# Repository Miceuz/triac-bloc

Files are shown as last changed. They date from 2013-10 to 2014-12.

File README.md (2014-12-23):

triac-bloc
==========

A universal power block based on triac. In essence this is a high power solid state relay augmented with some bells and whistles. 

TRIAC BLOC

Bells and whistles:

 * Attiyny44 MCU on board
 * I2C interface
 * maximum power - 6kW
 * zero crossing detection
 * controllable via I2C protocol
 * phase shift dimmer mode
 * linear output power control
 * switch at zero-crossing mode
 * output filtering for dimmer mode
 * snubber network
 * “low level” zero-crossing signal output
 * “low level” triac trigger signal input
 * 4 spare MCU pins available for additional features
 * open source hardware and firmware

More info available at: http://wemakethings.net/2013/10/27/triac-bloc/

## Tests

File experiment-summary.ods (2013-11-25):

input R | pull up R | ZC pulse |  |  |  |  |  | Period length
 |  | mean | median | min | max | Max-min | diff abs median | mean | median | min | max | Max-min | diff abs median
32.8k | 47k | 0.359 | 0.358 | 0.335 | 0.371 | 0.036 | 0.001875 | 9.9778 | 9.9775 | 9.923 | 10.0415 | 0.1185 | 0.037
32.8k | 10k | 0.54 | 0.54 | 0.494 | 0.561 | 0.067 | 0.003975 | 9.9788 | 9.9620 | 9.939 | 10.0175 | 0.0785 | 0.059
16.4k | 10k | 0.302 | 0.302 | 0.280 | 0.312 | 0.032 | 0.001625 | 9.9781 | 9.9770 | 9.917 | 10.0750 | 0.1585 | 0.029
16.4k | 1k | 1.1598 | 1.164 | 1.102 | 1.205 | 0.103 | 0.001969

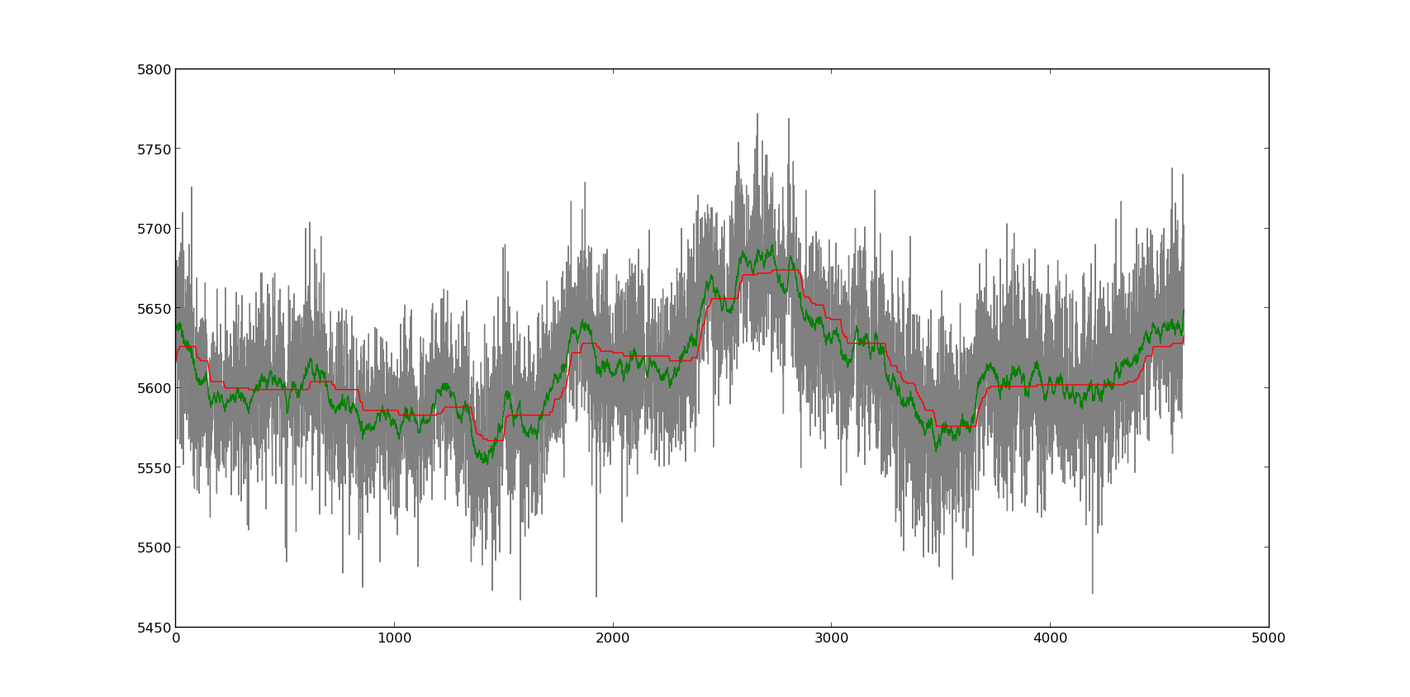
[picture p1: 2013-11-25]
experiment2/zc-pulse-length-noise3.png

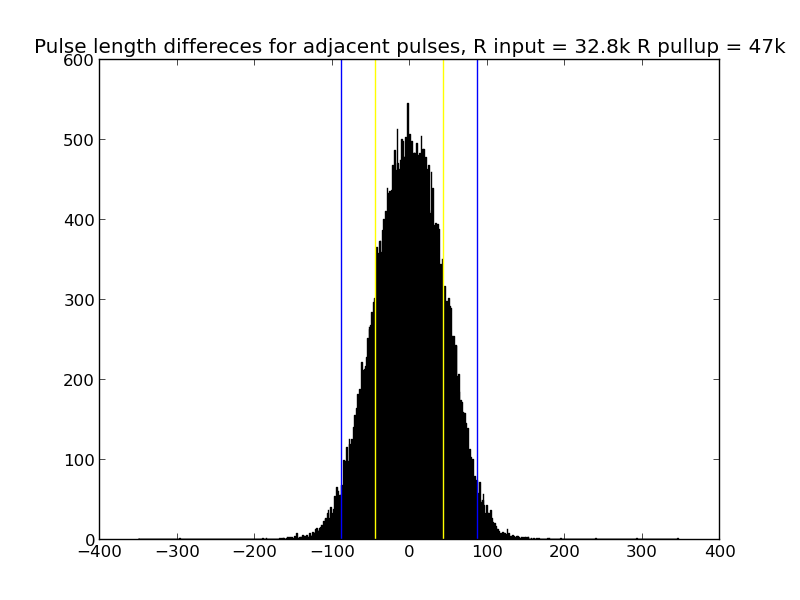
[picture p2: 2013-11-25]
experiment2/Pulse length differeces for adjacent pulses, R input = 32k8 R pullup = 47k.png

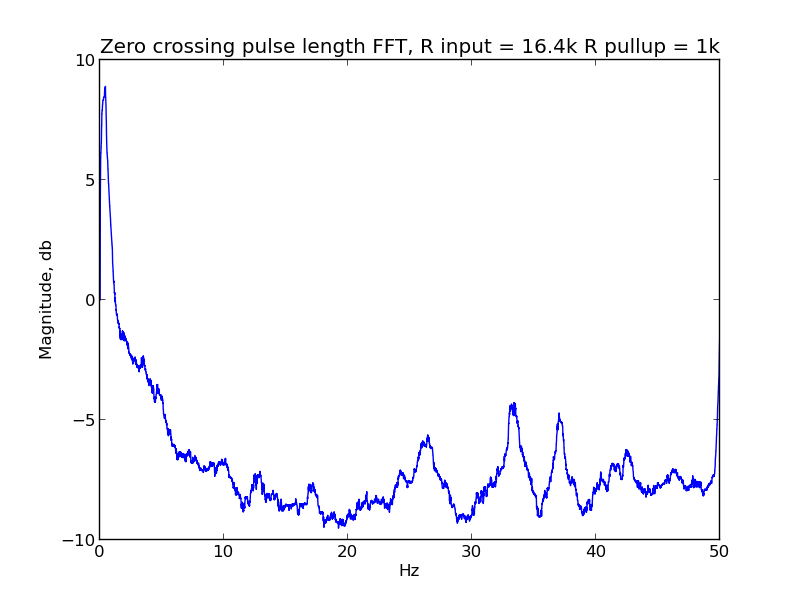
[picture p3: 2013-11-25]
experiment3/Zero crossing pulse length FFT, R input = 16k4 R pullup = 1k.png

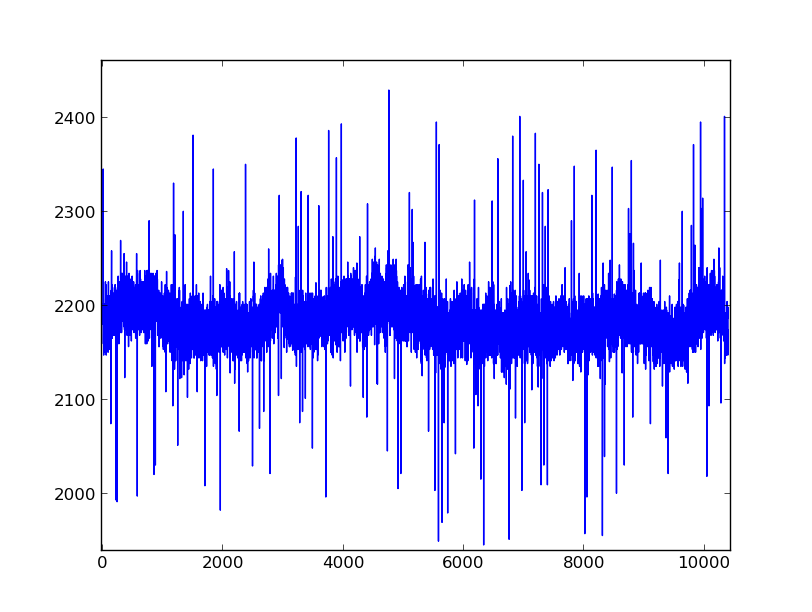
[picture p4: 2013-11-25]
experiment2/zc-pulse-length-noise.png

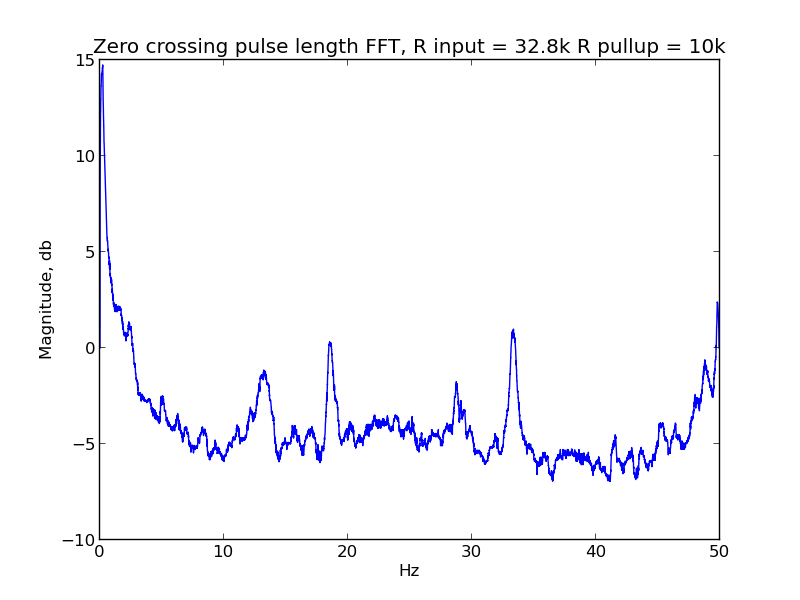
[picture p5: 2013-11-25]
experiment3/Zero crossing pulse length FFT, R input = 32k8 R pullup = 10k.png

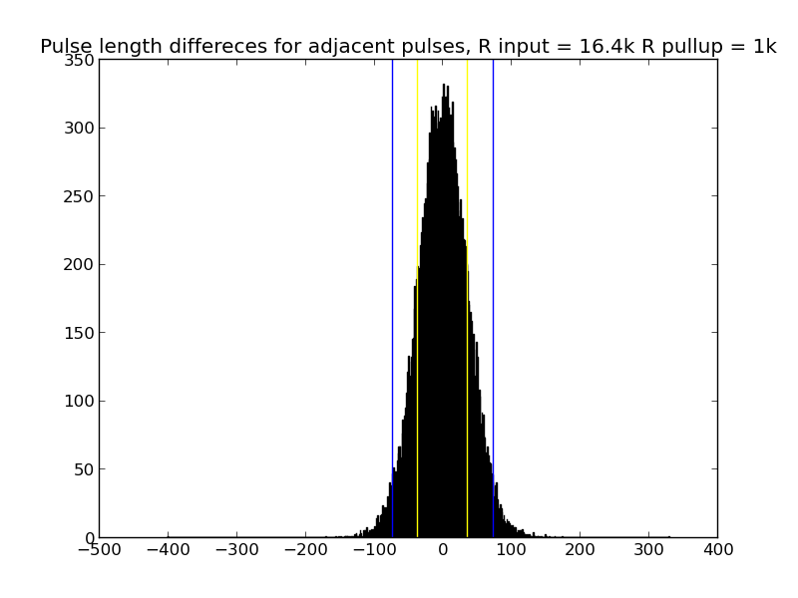
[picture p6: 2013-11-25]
experiment2/Pulse length differeces for adjacent pulses, R input = 16k4 R pullup = 1k.png

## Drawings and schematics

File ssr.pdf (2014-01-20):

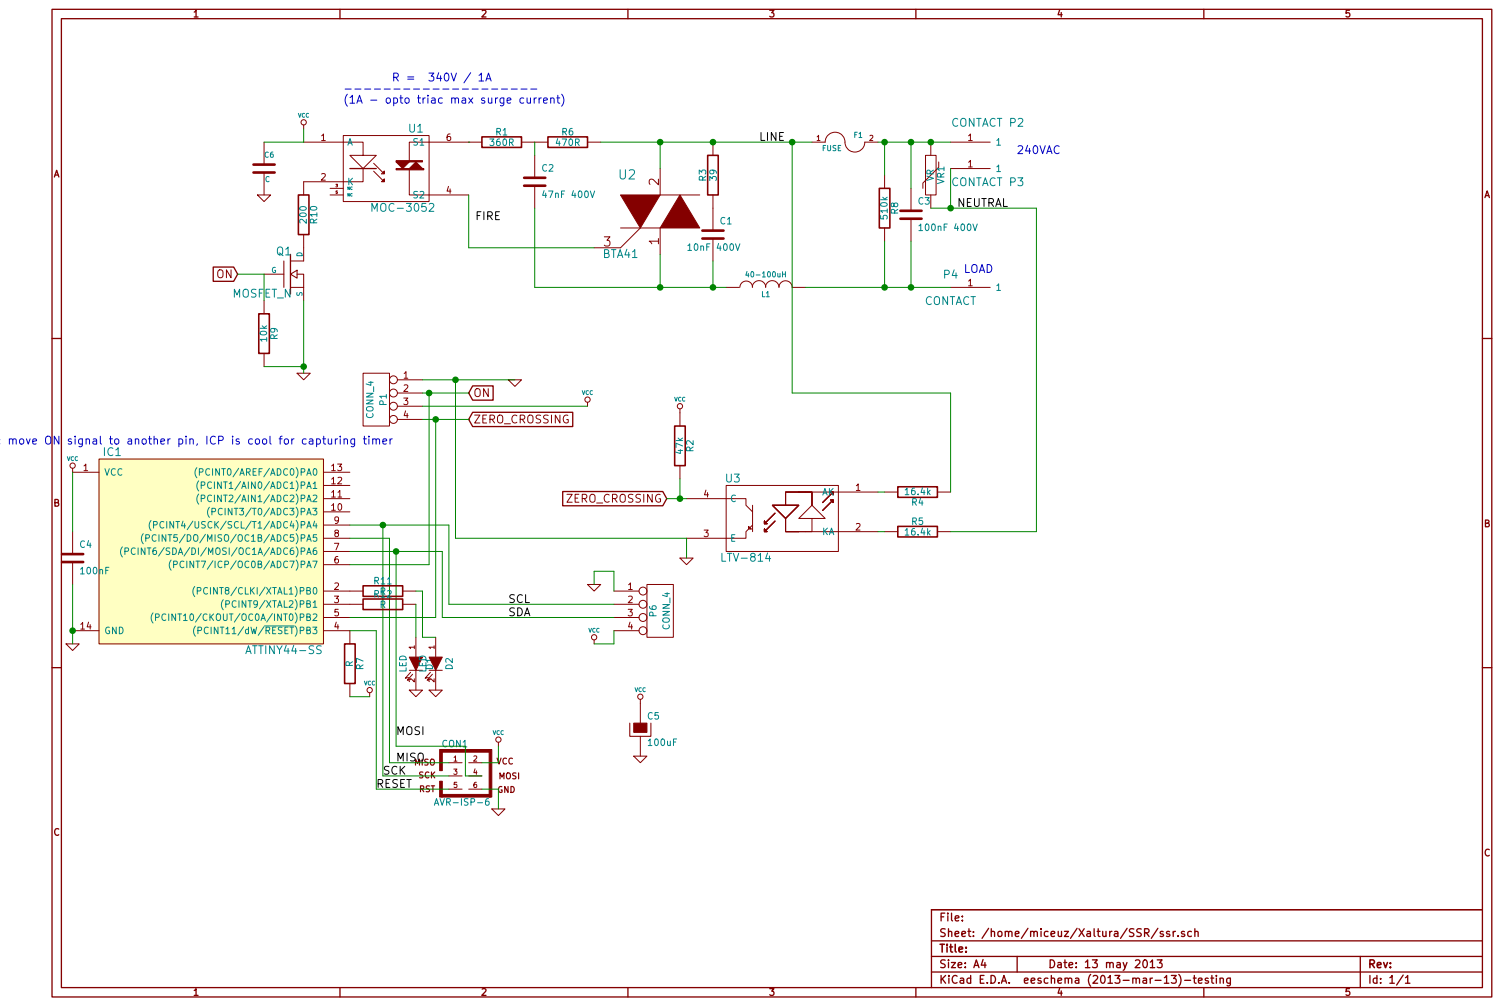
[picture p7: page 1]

TODO: move ON signal to another pin, ICP is cool for capturing timer

C Sheet: /home/miceuz/Xaltura/SSR/ssr.sch File: Title:

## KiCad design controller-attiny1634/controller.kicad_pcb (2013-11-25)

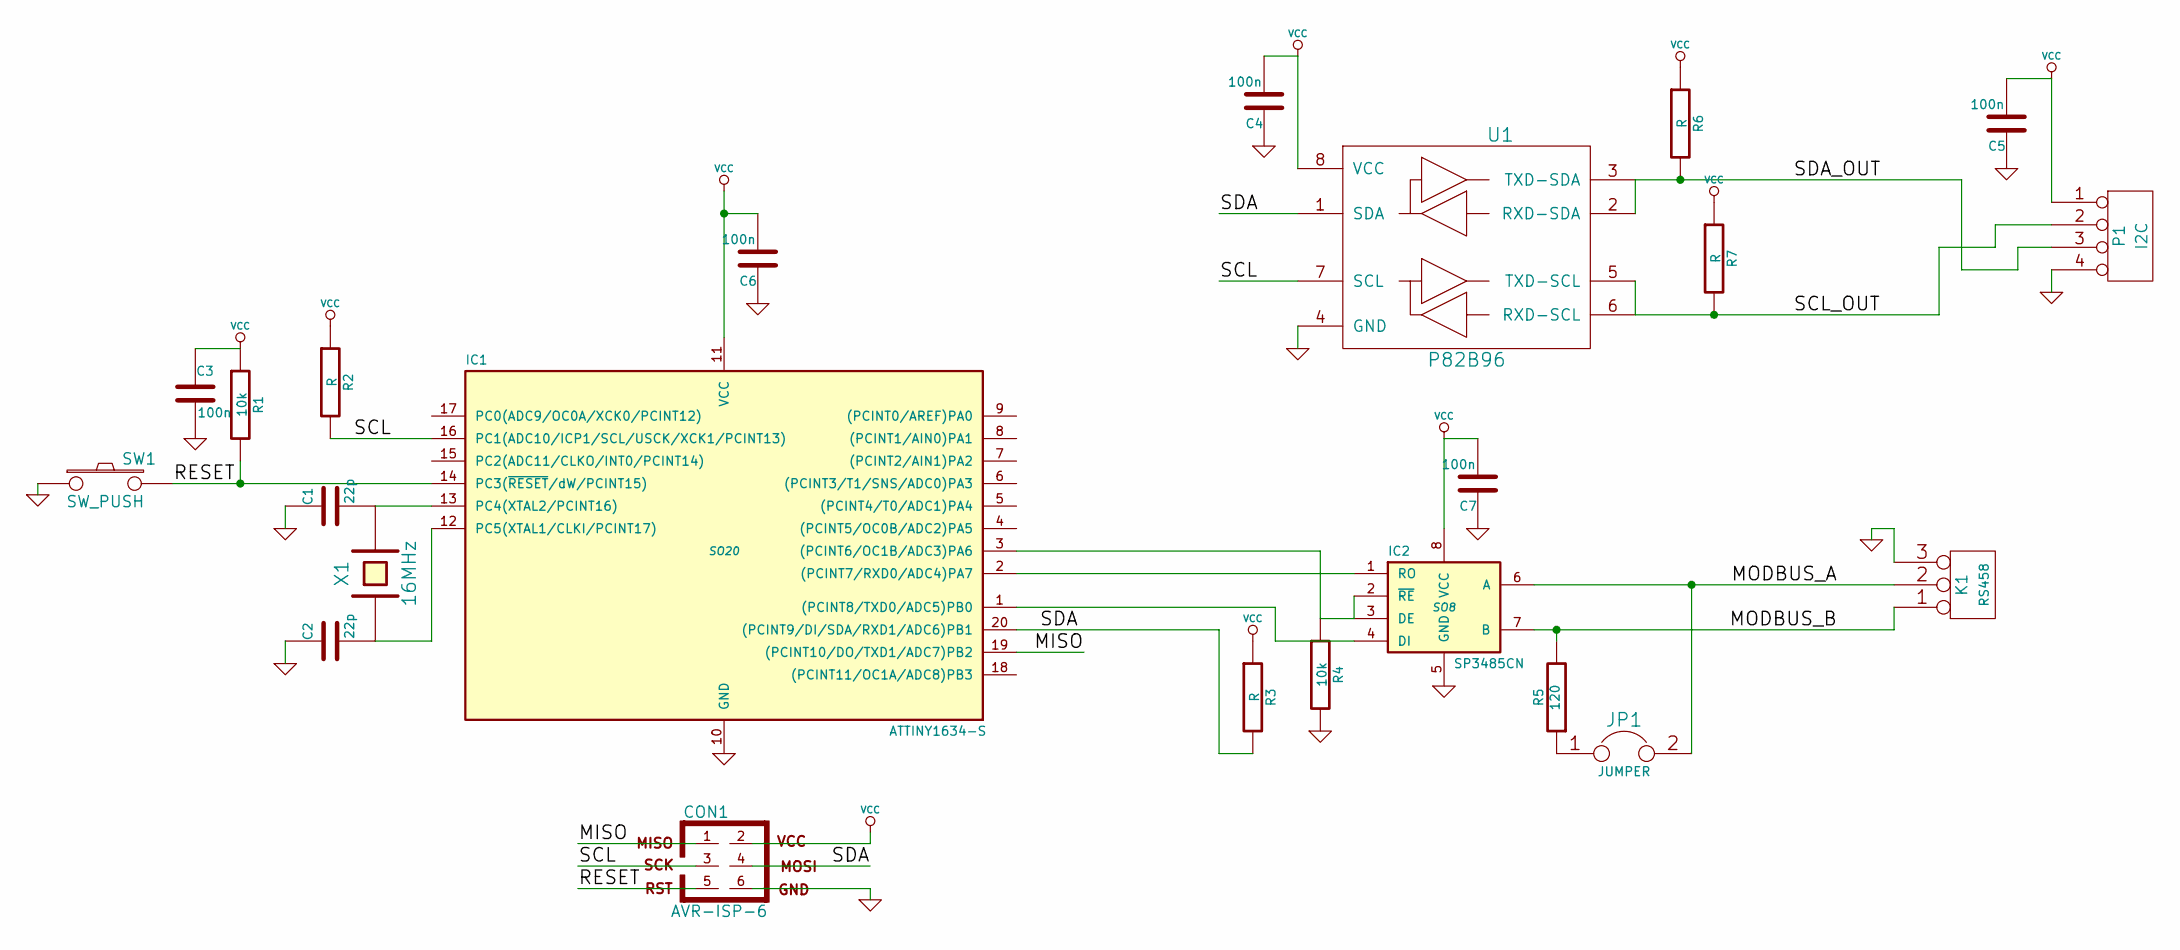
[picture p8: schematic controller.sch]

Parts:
C1, C2: 22p
C3, C4, C5, C6, C7: 100n
CON1: AVR-ISP-6
IC1: ATTINY1634-S; SO20
IC2: SP3485CN; SO8
JP1: JUMPER
K1: RS458
P1: I2C
R1, R4: 10k
R2, R3, R6, R7: R
R5: 120
SW1: SW_PUSH
U1: P82B96
X1: 16MHz

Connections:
/MISO: CON1.1, IC1.19 ((PCINT10/DO/TXD1/ADC7)PB2)
/MODBUS_A: IC2.6 (A), JP1.2, K1.2 (PM)
/MODBUS_B: IC2.7 (B), K1.1, R5.2
/RESET: CON1.5, IC1.14 (PC3(~RESET~/dW/PCINT15)), R1.2, SW1.2
/SCL: CON1.3, IC1.16 (PC1(ADC10/ICP1/SCL/USCK/XCK1/PCINT13)), R2.2, U1.7 (SCL)
/SCL_OUT: P1.2, R7.2, U1.5 (TXD-SCL), U1.6 (RXD-SCL)
/SDA: CON1.4, IC1.20 ((PCINT9/DI/SDA/RXD1/ADC6)PB1), R3.2, U1.1 (SDA)
/SDA_OUT: P1.3, R6.2, U1.2 (RXD-SDA), U1.3 (TXD-SDA)
GND: C1.1, C2.1, C3.2, C4.1, C5.1, C6.1, C7.1, CON1.6, IC1.10 (GND), IC2.5 (GND), K1.3, P1.4, R4.2, SW1.1, U1.4 (GND)
unnamed: C1.2, IC1.13 (PC4(XTAL2/PCINT16)), X1.2
unnamed: C2.2, IC1.12 (PC5(XTAL1/CLKI/PCINT17)), X1.1
unnamed: IC1.2 ((PCINT7/RXD0/ADC4)PA7), IC2.1 (RO)
unnamed: JP1.1, R5.1
unnamed: IC1.3 ((PCINT6/OC1B/ADC3)PA6), IC2.2 (~RE~), IC2.3 (DE), R4.1
unnamed: IC1.1 ((PCINT8/TXD0/ADC5)PB0), IC2.4 (DI)
VCC: C3.1, C4.2, C5.2, C6.2, C7.2, CON1.2, IC1.11 (VCC), IC2.8 (VCC), P1.1, R1.1, R2.1, R3.1, R6.1, R7.1, U1.8 (VCC)

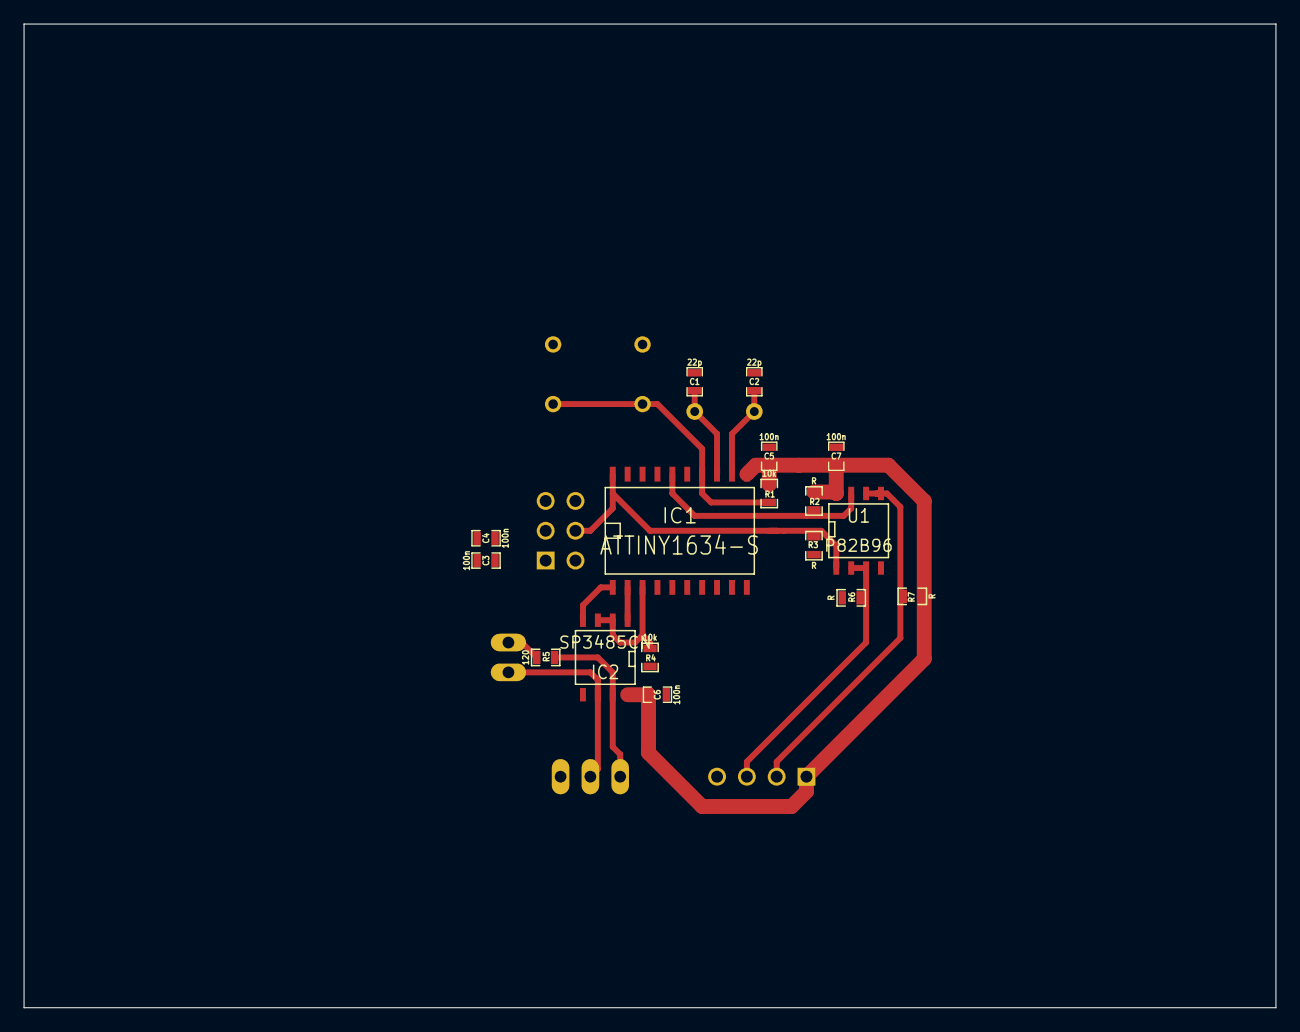
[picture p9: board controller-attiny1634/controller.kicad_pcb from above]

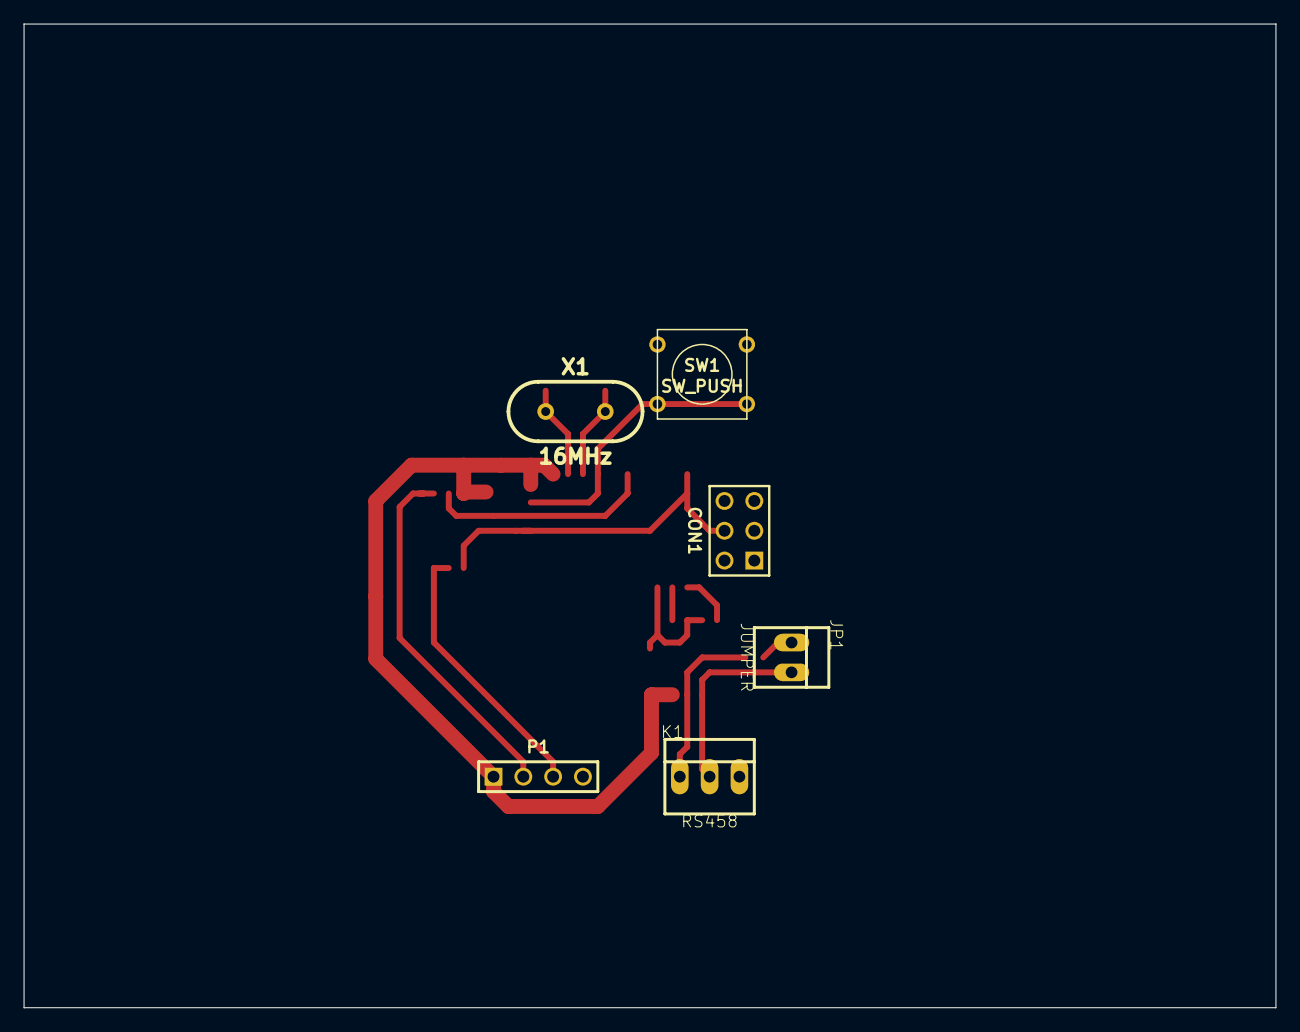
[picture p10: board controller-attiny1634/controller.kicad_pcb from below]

Board: 2 copper layers, 106.7 x 83.8 mm, 23 parts (6 on the bottom side), 16 nets.

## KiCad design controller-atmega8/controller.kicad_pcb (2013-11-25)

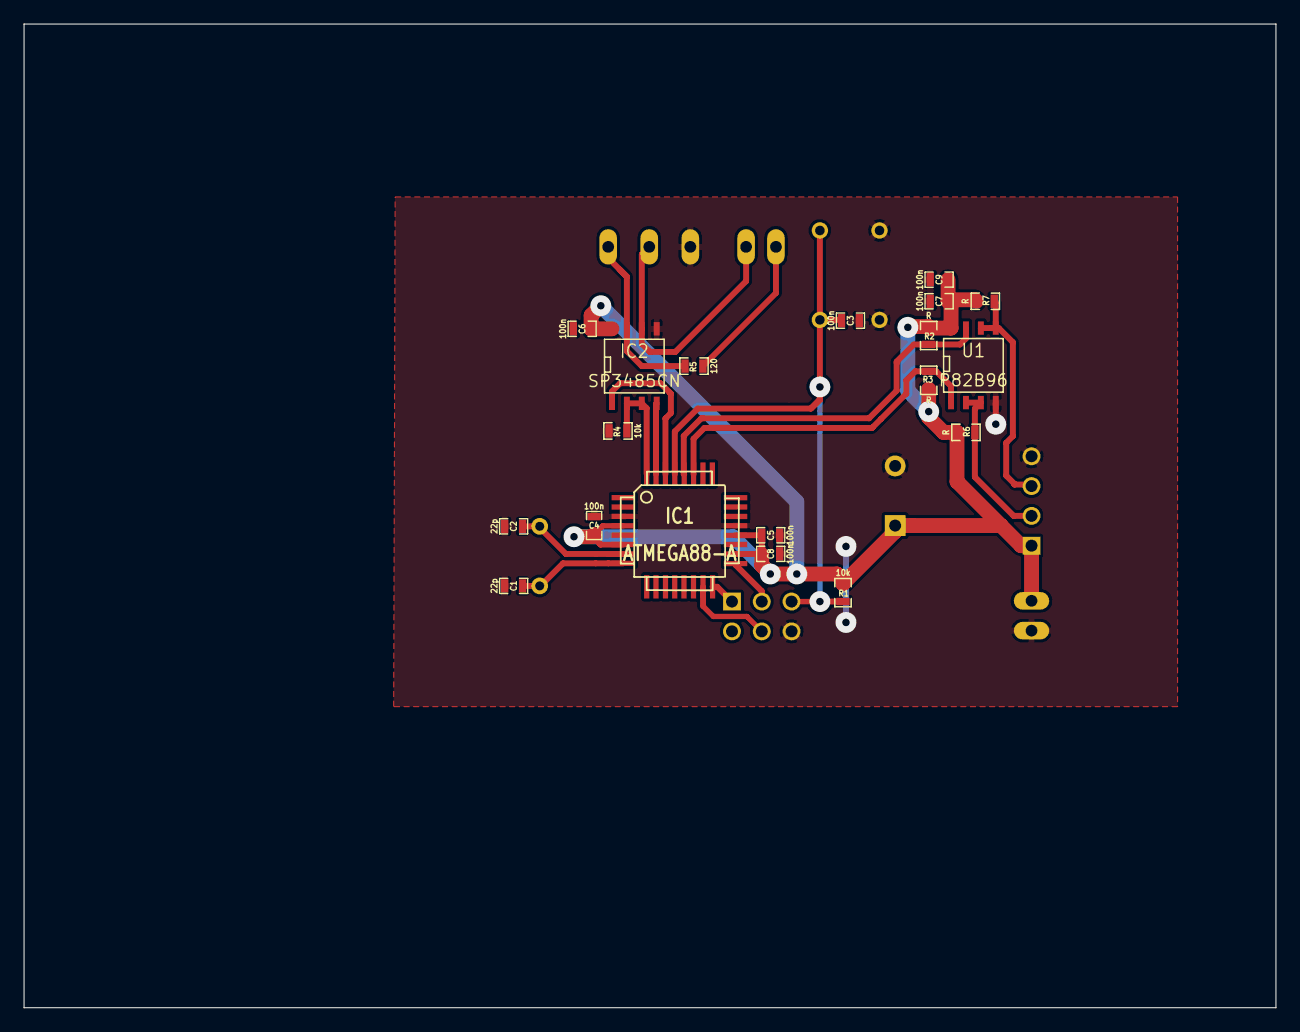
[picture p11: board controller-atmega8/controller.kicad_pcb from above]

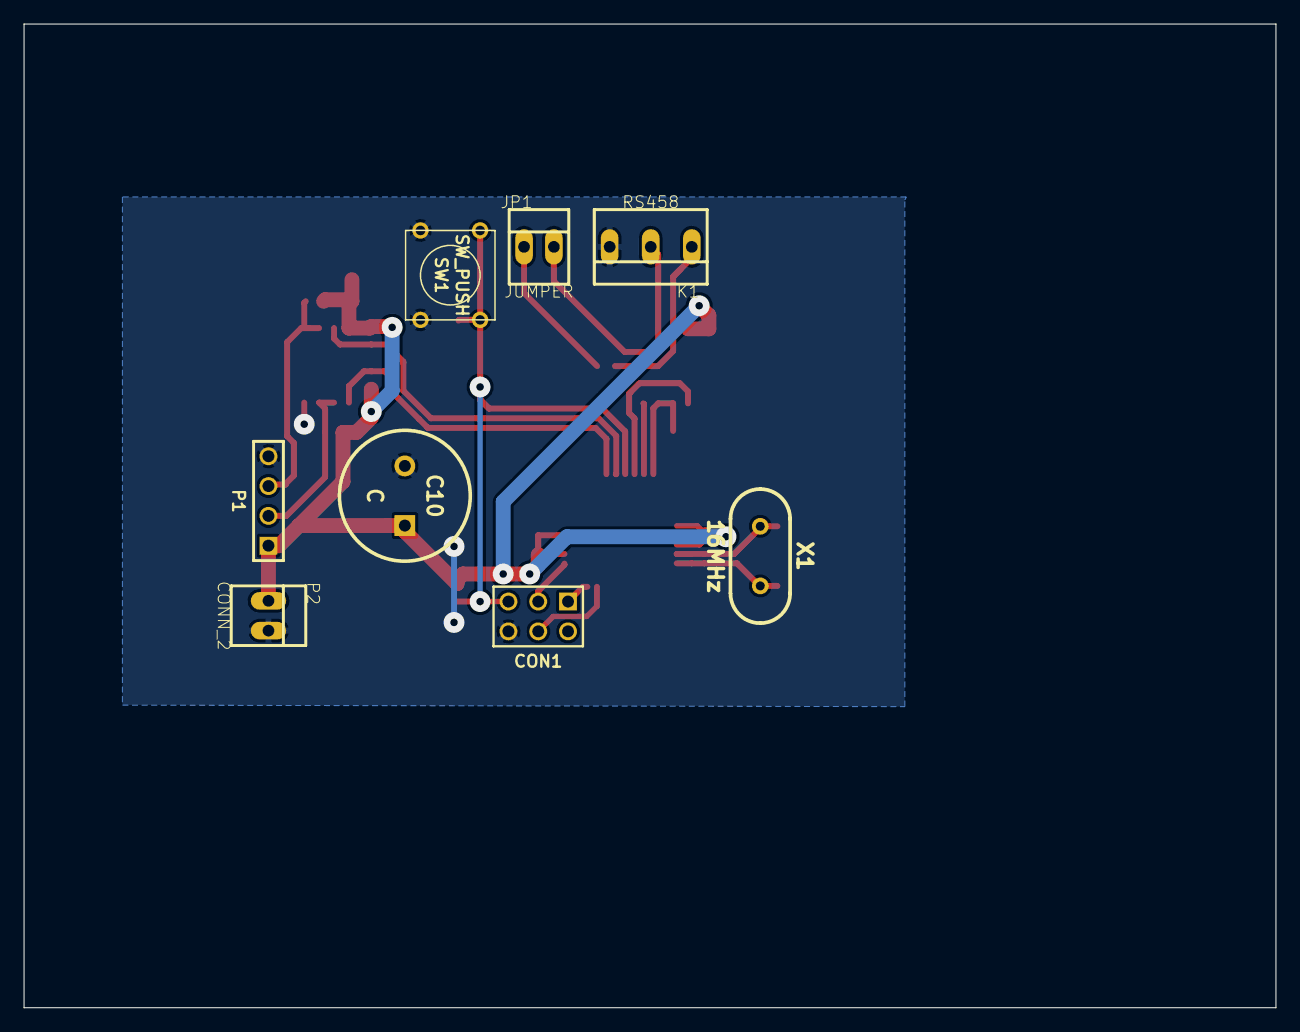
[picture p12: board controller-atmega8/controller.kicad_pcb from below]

Board: 2 copper layers, 106.7 x 83.8 mm, 27 parts (8 on the bottom side), 18 nets.

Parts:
C1, C2: 22p; SM0603_Capa
C3, C4, C5, C6, C7, C8, C9: 100n; SM0603_Capa
C10: C; C2V10
CON1: AVR-ISP-6; pin_array_3x2
IC1: ATMEGA88-A; TQFP32
IC2: SP3485CN; SO8N
JP1: JUMPER; PINHEAD1-2
K1: RS458; PINHEAD1-3
P1: I2C; PIN_ARRAY_4x1
P2: CONN_2; PINHEAD1-2
R1, R4: 10k; SM0603_Resistor
R2, R3, R6, R7: R; SM0603_Resistor
R5: 120; SM0603_Resistor
SW1: SW_PUSH; SW_PUSH_SMALL
U1: P82B96; SO8N
X1: 16MHz; HC-49V

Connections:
/DRIVER_ENABLE: IC1.32, IC2.2, IC2.3, R4.1
/MISO: CON1.1, IC1.16
/MODBUS_A: IC2.6, JP1.2, K1.2
/MODBUS_B: IC2.7, K1.1, R5.2
/MOSI: CON1.4, IC1.15
/RESET: C3.1, CON1.5, IC1.29, R1.2, SW1.2
/SCK: CON1.3, IC1.17
/SCL: IC1.28, R2.2, U1.7
/SCL_OUT: P1.3, R7.2, U1.5, U1.6
/SDA: IC1.27, R3.2, U1.1
/SDA_OUT: P1.2, R6.2, U1.2, U1.3
GND: C1.1, C2.1, C3.2, C4.1, C5.1, C6.1, C7.1, C8.1, C9.1, C10.2, CON1.6, IC1.3, IC1.5, IC1.21, IC2.5, K1.3, P1.4, P2.2, R4.2, SW1.1, U1.4
unnamed: IC1.30, IC2.1
unnamed: IC1.31, IC2.4
unnamed: C2.2, IC1.7, X1.1
unnamed: C1.2, IC1.8, X1.2
unnamed: JP1.1, R5.1
VCC: C4.2, C5.2, C6.2, C7.2, C8.2, C9.2, C10.1, CON1.2, IC1.4, IC1.6, IC1.18, IC1.20, P1.1, P2.1, R1.1, R2.1, R3.1, R6.1, R7.1, U1.8

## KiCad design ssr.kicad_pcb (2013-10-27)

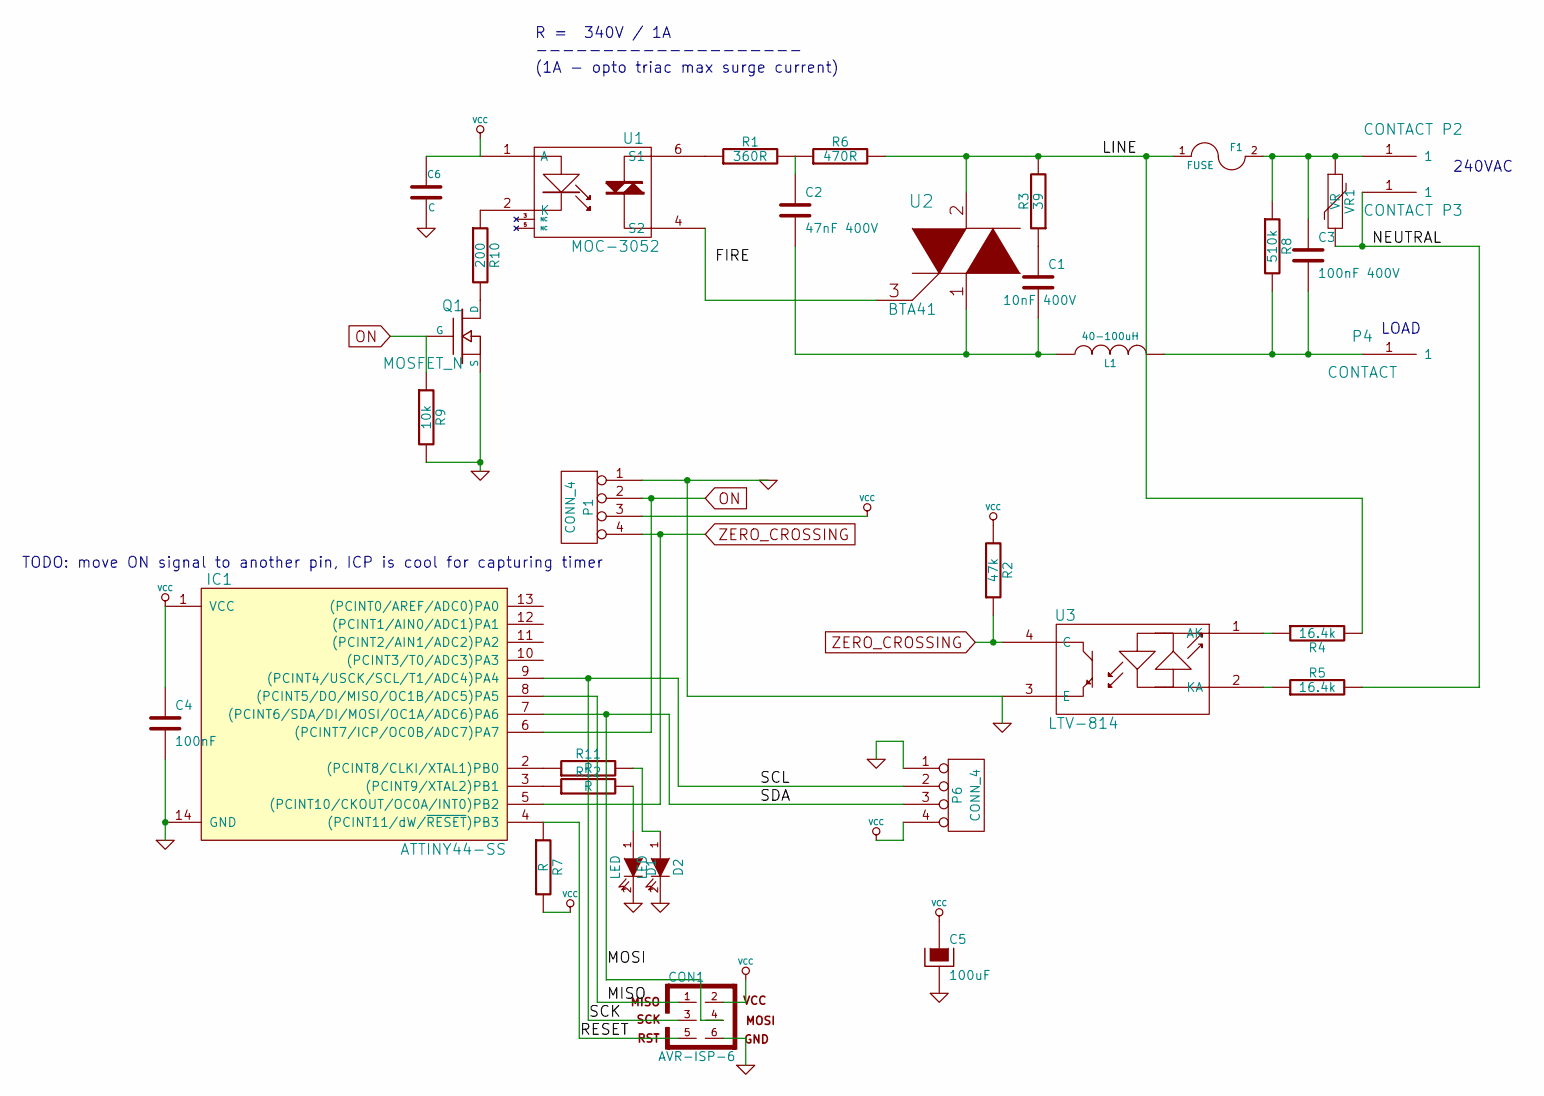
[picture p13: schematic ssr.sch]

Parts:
C1: 10nF 400V
C2: 47nF 400V
C3: 100nF 400V
C4: 100nF
C5: 100uF
C6: C
CON1: AVR-ISP-6
D1, D2: LED
F1: FUSE
IC1: ATTINY44-SS; SO14
L1: 40-100uH
P1, P6: CONN_4
P2, P3, P4: CONTACT
Q1: MOSFET_N
R1: 360R
R2: 47k
R3: 39
R4, R5: 16.4k
R6: 470R
R7, R11, R12: R
R8: 510k
R9: 10k
R10: 200
U1: MOC-3052
U2: BTA41
U3: LTV-814
VR1: VR

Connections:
/LINE: F1.1, F1.3, R3.2, R4.2, R6.2, U2.2
/MISO: CON1.1, IC1.8 ((PCINT5/DO/MISO/OC1B/ADC5)PA5)
/MOSI: CON1.4, IC1.7 ((PCINT6/SDA/DI/MOSI/OC1A/ADC6)PA6), P6.3
/NEUTRAL: P3.1, R5.2, VR1.2; also elsewhere on the board
/RESET: CON1.5, IC1.4 ((PCINT11/dW/~RESET~)PB3), R7.1
/SCK: CON1.3, IC1.9 ((PCINT4/USCK/SCL/T1/ADC4)PA4), P6.2
GND: C4.2, C5.2, C6.2, CON1.6, D1.2 (K), D2.2 (K), IC1.14 (GND), P1.1, P6.1, Q1.S, R9.2, U3.3 (E)
unnamed: U1.4 (S2), U2.3
unnamed: R5.1, U3.2 (KA)
unnamed: R4.1, U3.1 (AK)
unnamed: C2.1, R1.2, R6.1
unnamed: R1.1, U1.6 (S1)
unnamed: C1.2, C2.2, L1.1, U2.1
unnamed: IC1.2 ((PCINT8/CLKI/XTAL1)PB0), R11.1
unnamed: D2.1 (A), R11.2
unnamed: IC1.3 ((PCINT9/XTAL2)PB1), R12.1
unnamed: D1.1 (A), R12.2
unnamed: C3.2, L1.2, P4.1, R8.2
unnamed: R10.1, U1.2 (K)
unnamed: Q1.D, R10.2
unnamed: C3.1, F1.2, F1.4, F1.5, P2.1, R8.1, VR1.1
unnamed: C1.1, R3.1
ON: IC1.6 ((PCINT7/ICP/OC0B/ADC7)PA7), P1.2, Q1.G, R9.1
VCC: C4.1, C5.1, C6.1, CON1.2, IC1.1 (VCC), P1.3, P6.4, R2.2, R7.2, U1.1 (A)
ZERO_CROSSING: IC1.5 ((PCINT10/CKOUT/OC0A/INT0)PB2), P1.4, R2.1, U3.4 (C)

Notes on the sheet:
240VAC
LOAD
R = 340V / 1A -------------------- (1A - opto triac max surge current)
TODO: move ON signal to another pin, ICP is cool for capturing timer

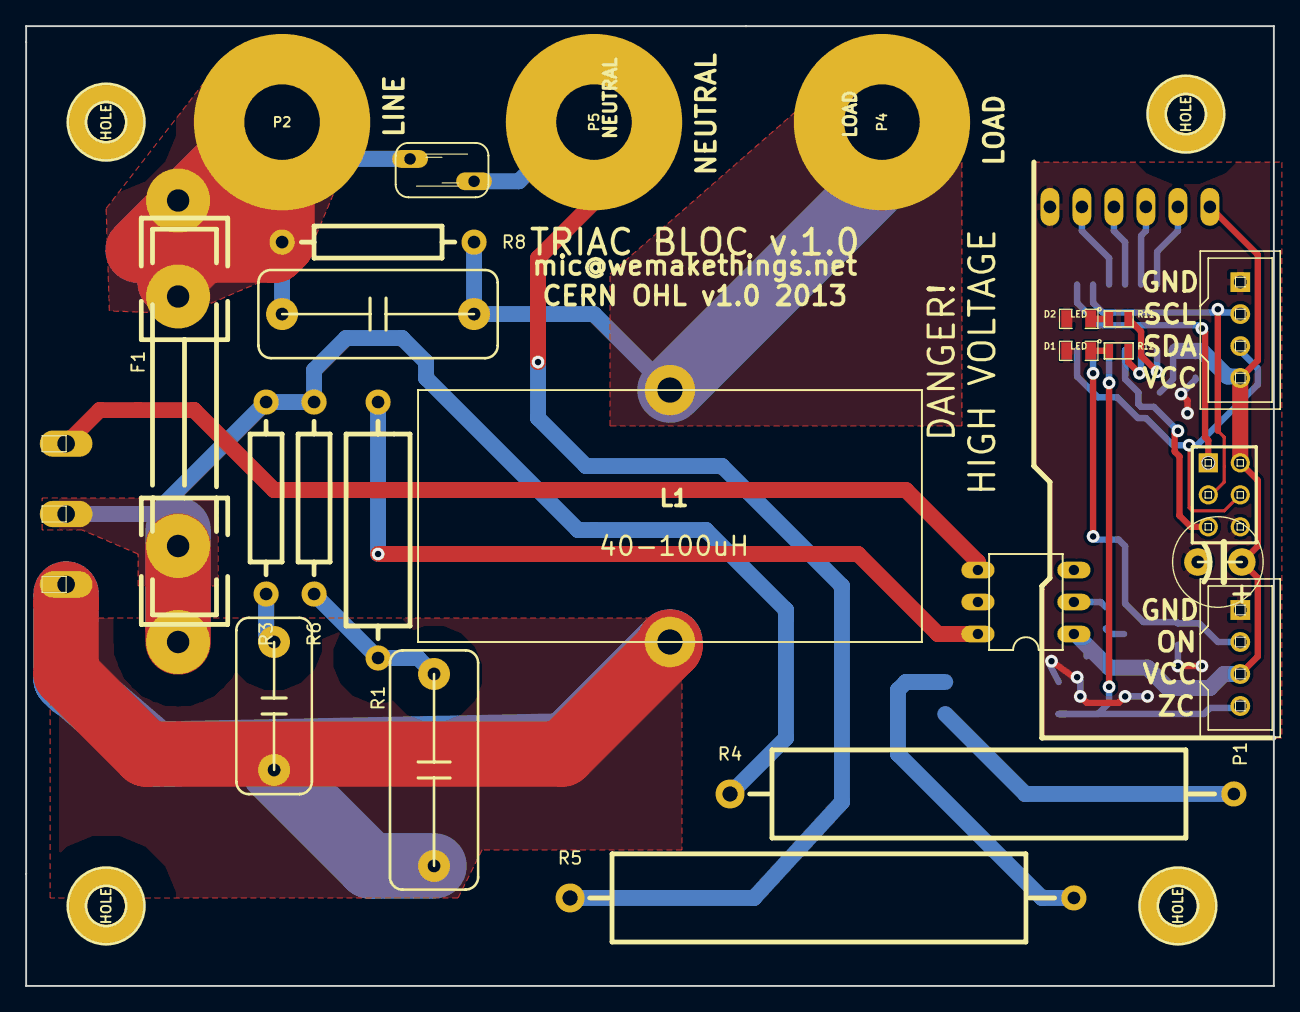
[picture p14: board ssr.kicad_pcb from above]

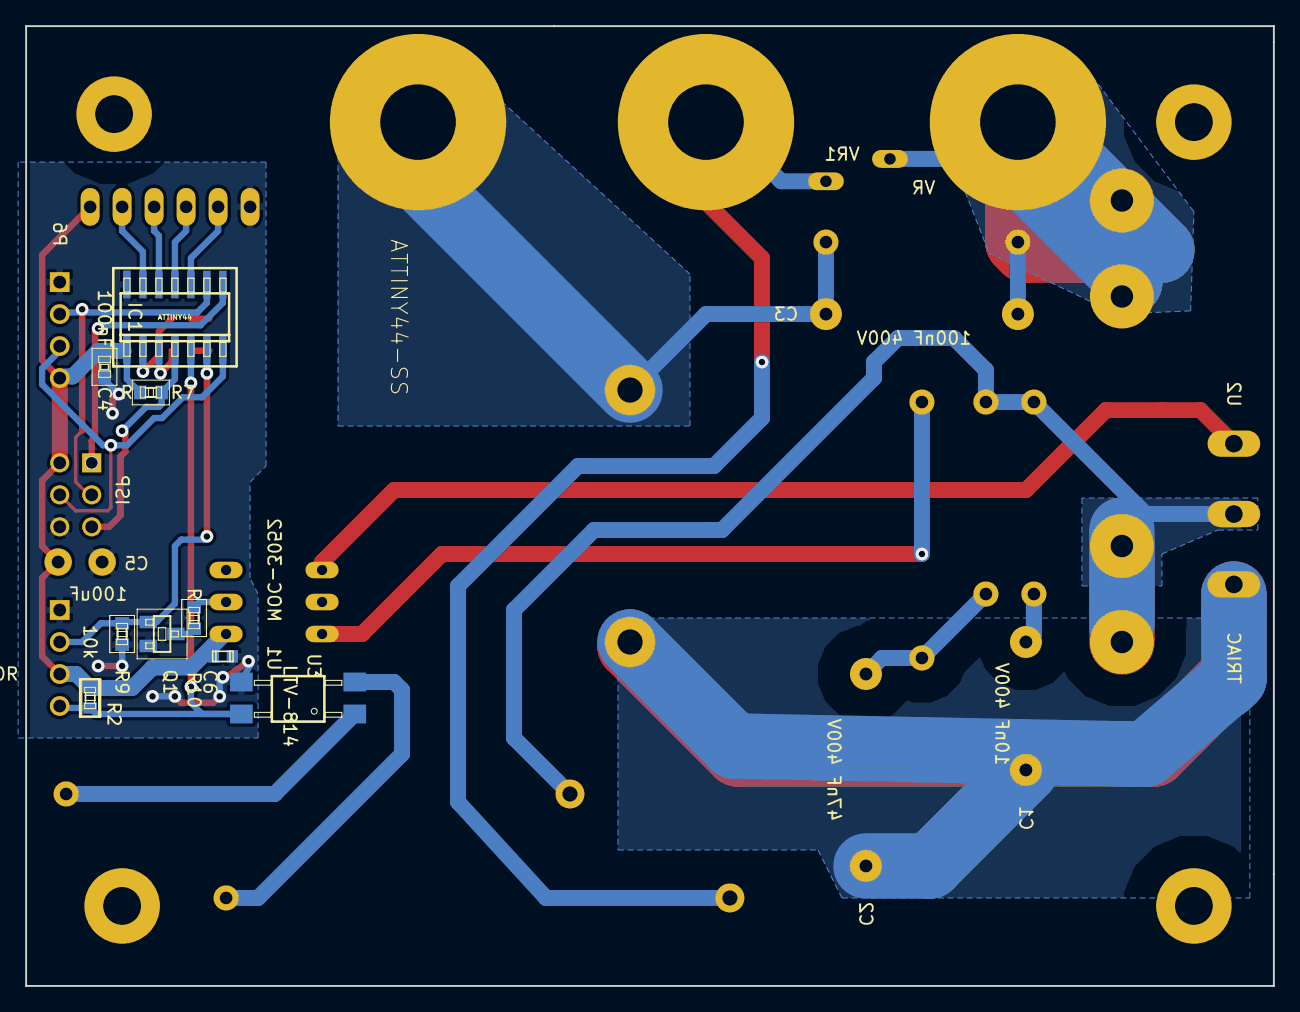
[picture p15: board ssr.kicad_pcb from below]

Board: 2 copper layers, 99.1 x 76.2 mm, 37 parts (9 on the bottom side), 24 nets.

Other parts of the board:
HOLE: Val**; HOLE_30
HOLE#2, HOLE#3, HOLE#4: Val**; HOLE_30
P5: CONTACT; HOLE_60

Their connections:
/NEUTRAL: P5.1; also elsewhere on the board

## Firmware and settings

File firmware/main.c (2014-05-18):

#include <inttypes.h>
#include <avr/io.h>
#include <stdlib.h>
#include <util/delay.h>
#include <avr/interrupt.h>
#include <avr/wdt.h>
#include <avr/sleep.h>
#include <avr/pgmspace.h>
#include <avr/wdt.h>
#include <avr/eeprom.h>
#include "usiTwiSlave.h"

#define GREEN PB0
#define RED PB1

/*
 * Sets the linear output power in dimmer mode. 1 byte argument: [0 - 255]
 */
#define I2C_SET_DIMMER_POWER 1
/*
 * Sets the linear output power in relay mode. 1 byte argument: [0 - 255]
 * In relay mode conduction is switched on after each ZC for the whole period {relayOutputPower} times in a row out of RELAY_MAX_POWER
 * thus, imitating a dimmer without causing electrical noise.
 */
#define I2C_SET_RELAY_POWER 2
/*
 * Directly sets the conduction angle. 2 bytes argument: [0 - 1000]
 */
#define I2C_SET_CONDUCTION_ANGLE 3
/*
 * Returns 2 bytes of filtered period length, represents the number of
 * internal timer ticks between two zero crossings.
 * Should be around 10000.
 * */
#define I2C_READ_PERIOD_LENGTH 4
/**
 * Returns 2 bytes of zero crossing pulse length.
 */
#define I2C_READ_ZC_PULSE_LENGHT 5
/**
 * Returns the 1 byte value of processor speed calibration register.
 */
#define I2C_READ_OSCCAL 6
/**
 * Returns 2 bytes of currently set conduction angle [0 - 10000]
 */
#define I2C_READ_CONDUCTION_ANGLE 7
/*
 * Returns 2 bytes of last period length, represents the number of
 * internal timer ticks between two zero crossings.
 * Should be around 10000.
 * */
#define I2C_READ_LAST_PERIOD_LENGTH 8
/**
 * Resets the Triac Bloc
 */
#define I2C_RESET 9
/**
 * Starts the calibration routine.
 * Red and green leds blink alternatingly while calibration is in progress.
 * Might take a while.
 */
#define I2C_CALIBRATE 10
#define I2C_ADC 11
/**
 * A routine for testing I2C connection. Both red and green leds will light up for a second.
 */
#define I2C_TEST 12

#define reset() wdt_enable(WDTO_15MS); while(1) {}

inline void conductionOn();
inline void conductionOff();
inline void setupZCInterrupt();
inline void setTimerInterruptAt(const uint16_t countTo, const uint8_t nextEvent);
inline void stopTimer();

#define NEVER 0
#define EVENT_TRUE_ZC 1
#define EVENT_CONDUCT 2

volatile uint8_t interruptAt = NEVER;
volatile uint16_t conductionAngle = 9000;
volatile uint16_t newConductionAngle = 9000;
volatile uint16_t zcPulseLength = 0;
volatile uint16_t periodLength = 0;
volatile uint8_t oscAjdustDelayCounter = 0;
volatile uint16_t zcInterruptTimestamp = 0;
extern const uint16_t conductionAngles[256];

#define EDGE_LEADING 0
#define EDGE_FALLING 1
#define MAX_SANE_ZC_LENGTH_DIFF 5
#define true 1
#define false 0

uint8_t zcInterruptEdge = EDGE_LEADING;
uint8_t powerGood = false;
uint8_t calibrationGood = false;

volatile uint8_t fadeIn = 1;
volatile uint8_t j = 255;
void fadeInOut() {
	if(fadeIn) {
		j --;
		if(j < 1) {
			fadeIn = !fadeIn;
		}
	} else {
		j ++;
		if(j > 254) {
			fadeIn = !fadeIn;
		}
	}
	newConductionAngle = pgm_read_word(&conductionAngles[j]);
}

inline void conductionOn() {
	PORTA |= _BV(PA7);
}

inline void conductionOff() {
	PORTA &= ~_BV(PA7);
}

inline void resetTimer() {
	TCNT1 = 0;
}

inline void setTimerInterruptAt(const uint16_t countTo, const uint8_t nextEvent) {
	TIMSK1 |= _BV(OCIE1A) | _BV(TOIE1);
	OCR1A = countTo;
	TCCR1B |= _BV(CS11); //fmcu/8 = 1Mhz == 10000 counts per period
	interruptAt = nextEvent;
}

inline void stopTimer() {
	TCCR1B = 0;
}

inline void continueTimer() {
	TCCR1B |= _BV(CS11); //fmcu/8 = 1Mhz == 10000 counts per period
}

//Timer interrupt - happens at various events in life
ISR(TIM1_COMPA_vect) {
	if(EVENT_TRUE_ZC == interruptAt) {
		stopTimer();
		setTimerInterruptAt(TCNT1 + conductionAngle, EVENT_CONDUCT);
	} else {// if(EVENT_CONDUCT == interruptAt)
		conductionOn();
	}
}

//Timer overflow means - there is no ZC interrupt happening and setting up EVENT_TRUE_ZC timer.
ISR(TIM1_OVF_vect) {
	conductionOff();
	stopTimer();
	powerGood = false;
}

inline void saveCalibration(){
	eeprom_write_byte(0x00, OSCCAL);
}

inline void adjustOscillatorSpeed() {
	if (oscAjdustDelayCounter++ > 128) {
		if(periodLength > 10060) {
			OSCCAL--;
			calibrationGood = false;
		} else if(periodLength < 9940){
			OSCCAL++;
			calibrationGood = false;
		} else {
			calibrationGood = true;
		}
		oscAjdustDelayCounter = 0;
	}
}

volatile int32_t periodFiltered = 0;
volatile int32_t periodFiltered2 = 0;

inline uint16_t filterPeriodLength(int32_t thisPeriodLength) {
	if(0 != periodFiltered2) {
		periodFiltered = periodFiltered	+ ((thisPeriodLength - periodFiltered) >> 5);
		periodFiltered2 = periodFiltered2 + ((periodFiltered - periodFiltered2) >> 5);
	} else {
		periodFiltered = thisPeriodLength;
		periodFiltered2 = thisPeriodLength;
	}
	return (uint16_t) periodFiltered2;
}

inline void setupZCInterrupt() {
	MCUCR |= _BV(ISC01) | _BV(ISC00);
	GIMSK |= _BV(INT0);
	zcInterruptEdge = EDGE_LEADING;
}

inline void flipZcInterruptEdge() {
	zcInterruptEdge = !zcInterruptEdge;
	MCUCR = MCUCR ^ 1; //flip last bit, changing the edge for the next intettupt
}

#define MODE_DIMMER 1
#define MODE_RELAY  2
#define RELAY_MAX_CYCLES 255

uint8_t relayOnCycles = 0;
uint8_t mode = MODE_DIMMER;
uint8_t relayOutputPower = 0;

inline uint16_t getNewConductionAngle() {
	if(MODE_DIMMER == mode) {
		return newConductionAngle;
	} else {
		//MODE_RELAY
		if(relayOnCycles > RELAY_MAX_CYCLES) {
			relayOnCycles = 0;
		}

		if(relayOnCycles++ >= relayOutputPower) {
			return 9000;//min power
		} else {
			return 0;//max power
		}
	}
}

//Zero crossing interrupt: collects statistics, restarts the timer - next stop - true zero crossing interrupt
ISR(EXT_INT0_vect) {
	stopTimer();

	if(EDGE_LEADING == zcInterruptEdge) {
		//fadeInOut();
		conductionOff();
		stopTimer();
		periodLength = filterPeriodLength(TCNT1);
		zcInterruptTimestamp = TCNT1;
		resetTimer();
		conductionAngle = getNewConductionAngle();
		setTimerInterruptAt(zcPulseLength >> 1, EVENT_TRUE_ZC);
		adjustOscillatorSpeed();
	} else {
		uint8_t lastZcPulseLength = TCNT1;
		continueTimer();
		int diff = abs(zcPulseLength - lastZcPulseLength);
		if (diff < MAX_SANE_ZC_LENGTH_DIFF || 0 == zcPulseLength) {
			zcPulseLength = lastZcPulseLength;
		}
	}
	flipZcInterruptEdge();
	powerGood=1;
}

inline void ledOn(uint8_t led){
	PORTB |= _BV(led);
}

inline void ledOff(uint8_t led){
	PORTB &= ~_BV(led);
}

inline void calibrate() {
	uint8_t calibration = eeprom_read_byte(0x00);
	if(calibration != 255) {
		OSCCAL = calibration;
	}

	while(!calibrationGood) {
		ledOn(RED);
		_delay_ms(300);
		ledOff(RED);
		ledOn(GREEN);
		_delay_ms(300);
		ledOff(GREEN);
	}
	eeprom_write_byte(0x00, OSCCAL);
}

uint8_t readAddressSetting() {
	DDRA &= 0b11110000;
	PORTA |= 0b00001111;
	_delay_ms(100);
	return ~PINA & 0b00001111;
}

int main (void) {
	MCUSR = 0;
	wdt_disable();
	DDRB |= _BV(RED) | _BV(GREEN);
	PORTB |= _BV(PB2);
	DDRA |= _BV(PA7);
	PORTA = 0;

	setupZCInterrupt();

	usiTwiSlaveInit(0x20 + readAddressSetting());
	sei();

	newConductionAngle = pgm_read_word(&conductionAngles[255]);

	while(1) {
		if(usiTwiDataInReceiveBuffer()) {
			uint8_t usiRx = usiTwiReceiveByte();
			if(I2C_SET_DIMMER_POWER == usiRx) {
				newConductionAngle = pgm_read_word(&conductionAngles[255 - usiTwiReceiveByte()]);
				mode = MODE_DIMMER;
			} else if(I2C_SET_RELAY_POWER == usiRx) {
				newConductionAngle = pgm_read_word(&conductionAngles[255]);
				relayOnCycles = 0;
				relayOutputPower = usiTwiReceiveByte();
				mode = MODE_RELAY;
			} else if (I2C_SET_CONDUCTION_ANGLE == usiRx) {
				newConductionAngle = ((uint16_t) usiTwiReceiveByte()) << 8;
				newConductionAngle |= (((uint16_t) usiTwiReceiveByte()) & 0x00FF);
			} else if (I2C_READ_PERIOD_LENGTH == usiRx){
				usiTwiTransmitByte(periodLength >> 8);
				usiTwiTransmitByte(periodLength & 0x00FF);
			} else if (I2C_READ_ZC_PULSE_LENGHT == usiRx){
				usiTwiTransmitByte(zcPulseLength >> 8);
				usiTwiTransmitByte(zcPulseLength & 0x00FF);
			} else if (I2C_READ_OSCCAL == usiRx){
				usiTwiTransmitByte(OSCCAL);
			} else if (I2C_READ_CONDUCTION_ANGLE == usiRx){
				usiTwiTransmitByte(conductionAngle >> 8);
				usiTwiTransmitByte(conductionAngle & 0x00FF);
			} else if (I2C_READ_LAST_PERIOD_LENGTH == usiRx){
				usiTwiTransmitByte(zcInterruptTimestamp >> 8);
				usiTwiTransmitByte(zcInterruptTimestamp & 0x00FF);
			} else if (I2C_RESET == usiRx) {
				reset();
			} else if(I2C_CALIBRATE == usiRx) {
				calibrate();
			} else if(I2C_TEST == usiRx) {
				ledOn(RED);
				ledOn(GREEN);
				_delay_ms(2000);
				ledOff(RED);
				ledOff(GREEN);
			}
		}

		if(!powerGood) {
			ledOn(RED);
			_delay_ms(100);
			ledOff(RED);
			_delay_ms(100);
		}
		ledOff(GREEN);
	}
}

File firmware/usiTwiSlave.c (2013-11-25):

/********************************************************************************

USI TWI Slave driver.

Created by Donald R. Blake
donblake at worldnet.att.net

---------------------------------------------------------------------------------

Created from Atmel source files for Application Note AVR312: Using the USI Module
as an I2C slave.

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
---------------------------------------------------------------------------------

Change Activity:

    Date       Description
   ------      -------------
  16 Mar 2007  Created.
  27 Mar 2007  Added support for ATtiny261, 461 and 861.
  26 Apr 2007  Fixed ACK of slave address on a read.
  04 Jul 2007  Fixed USISIF in ATtiny45 def
  05 Mar 2012  Added support for ATtiny24, 44, and 84.
  08 Mar 2012  Added support for START and STOP bit callbacks

********************************************************************************/



/********************************************************************************

                                    includes

********************************************************************************/

#include <avr/io.h>
#include <avr/interrupt.h>
#include "usiTwiSlave.h"



/********************************************************************************

                            device dependent defines

********************************************************************************/

#if defined( __AVR_ATtiny2313__ )
#  define DDR_USI             DDRB
#  define PORT_USI            PORTB
#  define PIN_USI             PINB
#  define PORT_USI_SDA        PB5
#  define PORT_USI_SCL        PB7
#  define PIN_USI_SDA         PINB5
#  define PIN_USI_SCL         PINB7
#  define USI_START_COND_INT  USISIF
#  define USI_START_VECTOR    USI_START_vect
#  define USI_OVERFLOW_VECTOR USI_OVERFLOW_vect
#endif

#if defined( __AVR_ATtiny24__ ) | \
     defined( __AVR_ATtiny44__ ) | \
     defined( __AVR_ATtiny84__ )
#  define DDR_USI             DDRA
#  define PORT_USI            PORTA
#  define PIN_USI             PINA
#  define PORT_USI_SDA        PA6
#  define PORT_USI_SCL        PA4
#  define PIN_USI_SDA         PINA6
#  define PIN_USI_SCL         PINA4
#  define USI_START_COND_INT  USISIF
#  define USI_START_VECTOR    USI_STR_vect
#  define USI_OVERFLOW_VECTOR USI_OVF_vect
#endif

#if defined( __AVR_ATtiny25__ ) | \
     defined( __AVR_ATtiny45__ ) | \
     defined( __AVR_ATtiny85__ )
#  define DDR_USI             DDRB
#  define PORT_USI            PORTB
#  define PIN_USI             PINB
#  define PORT_USI_SDA        PB0
#  define PORT_USI_SCL        PB2
#  define PIN_USI_SDA         PINB0
#  define PIN_USI_SCL         PINB2
#  define USI_START_COND_INT  USISIF
#  define USI_START_VECTOR    USI_START_vect
#  define USI_OVERFLOW_VECTOR USI_OVF_vect
#endif

#if defined( __AVR_ATtiny26__ )
#  define DDR_USI             DDRB
#  define PORT_USI            PORTB
#  define PIN_USI             PINB
#  define PORT_USI_SDA        PB0
#  define PORT_USI_SCL        PB2
#  define PIN_USI_SDA         PINB0
#  define PIN_USI_SCL         PINB2
#  define USI_START_COND_INT  USISIF
#  define USI_START_VECTOR    USI_STRT_vect
#  define USI_OVERFLOW_VECTOR USI_OVF_vect
#endif

#if defined( __AVR_ATtiny261__ ) | \
     defined( __AVR_ATtiny461__ ) | \
     defined( __AVR_ATtiny861__ )
#  define DDR_USI             DDRB
#  define PORT_USI            PORTB
#  define PIN_USI             PINB
#  define PORT_USI_SDA        PB0
#  define PORT_USI_SCL        PB2
#  define PIN_USI_SDA         PINB0
#  define PIN_USI_SCL         PINB2
#  define USI_START_COND_INT  USISIF
#  define USI_START_VECTOR    USI_START_vect
#  define USI_OVERFLOW_VECTOR USI_OVF_vect
#endif

#if defined( __AVR_ATmega165__ ) | \
     defined( __AVR_ATmega325__ ) | \
     defined( __AVR_ATmega3250__ ) | \
     defined( __AVR_ATmega645__ ) | \
     defined( __AVR_ATmega6450__ ) | \
     defined( __AVR_ATmega329__ ) | \
     defined( __AVR_ATmega3290__ )
#  define DDR_USI             DDRE
#  define PORT_USI            PORTE
#  define PIN_USI             PINE
#  define PORT_USI_SDA        PE5
#  define PORT_USI_SCL        PE4
#  define PIN_USI_SDA         PINE5
#  define PIN_USI_SCL         PINE4
#  define USI_START_COND_INT  USISIF
#  define USI_START_VECTOR    USI_START_vect
#  define USI_OVERFLOW_VECTOR USI_OVERFLOW_vect
#endif

#if defined( __AVR_ATmega169__ )
#  define DDR_USI             DDRE
#  define PORT_USI            PORTE
#  define PIN_USI             PINE
#  define PORT_USI_SDA        PE5
#  define PORT_USI_SCL        PE4
#  define PIN_USI_SDA         PINE5
#  define PIN_USI_SCL         PINE4
#  define USI_START_COND_INT  USISIF
#  define USI_START_VECTOR    USI_START_vect
#  define USI_OVERFLOW_VECTOR USI_OVERFLOW_vect
#endif



/********************************************************************************

                        functions implemented as macros

********************************************************************************/

#define SET_USI_TO_SEND_ACK( ) \
{ \
  /* prepare ACK */ \
  USIDR = 0; \
  /* set SDA as output */ \
  DDR_USI |= ( 1 << PORT_USI_SDA ); \
  /* clear all interrupt flags, except Start Cond */ \
  USISR = \
       ( 0 << USI_START_COND_INT ) | \
       ( 1 << USIOIF ) | ( 1 << USIPF ) | \
       ( 1 << USIDC )| \
       /* set USI counter to shift 1 bit */ \
       ( 0x0E << USICNT0 ); \
}

#define SET_USI_TO_READ_ACK( ) \
{ \
  /* set SDA as input */ \
  DDR_USI &= ~( 1 << PORT_USI_SDA ); \
  /* prepare ACK */ \
  USIDR = 0; \
  /* clear all interrupt flags, except Start Cond */ \
  USISR = \
       ( 0 << USI_START_COND_INT ) | \
       ( 1 << USIOIF ) | \
       ( 1 << USIPF ) | \
       ( 1 << USIDC ) | \
       /* set USI counter to shift 1 bit */ \
       ( 0x0E << USICNT0 ); \
}

#define SET_USI_TO_TWI_START_CONDITION_MODE( ) \
{ \
  USICR = \
       /* enable Start Condition Interrupt, disable Overflow Interrupt */ \
       ( 1 << USISIE ) | ( 0 << USIOIE ) | \
       /* set USI in Two-wire mode, no USI Counter overflow hold */ \
       ( 1 << USIWM1 ) | ( 0 << USIWM0 ) | \
       /* Shift Register Clock Source = External, positive edge */ \
       /* 4-Bit Counter Source = external, both edges */ \
       ( 1 << USICS1 ) | ( 0 << USICS0 ) | ( 0 << USICLK ) | \
       /* no toggle clock-port pin */ \
       ( 0 << USITC ); \
  USISR = \
        /* clear all interrupt flags, except Start Cond */ \
        ( 0 << USI_START_COND_INT ) | ( 1 << USIOIF ) | ( 1 << USIPF ) | \
        ( 1 << USIDC ) | ( 0x0 << USICNT0 ); \
}

#define SET_USI_TO_SEND_DATA( ) \
{ \
  /* set SDA as output */ \
  DDR_USI |=  ( 1 << PORT_USI_SDA ); \
  /* clear all interrupt flags, except Start Cond */ \
  USISR    =  \
       ( 0 << USI_START_COND_INT ) | ( 1 << USIOIF ) | ( 1 << USIPF ) | \
       ( 1 << USIDC) | \
       /* set USI to shift out 8 bits */ \
       ( 0x0 << USICNT0 ); \
}
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

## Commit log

2013-04-24 one more rearrangement of parts creepage distances taken care of homogenized via sizes part names and values taken care of
    [ssr.kicad_pcb]
2013-04-26 this commit is a mess
    [ssr.kicad_pcb, ssr.sch]
2013-05-07 boards sent for manufacture
    [ssr-B_Cu.gbl, ssr-B_Mask.gbs, ssr-B_SilkS.gbo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]
2013-06-22 power output linearization
2013-10-27 some work on firmware, experiments, some documentation has been added
    [ssr.kicad_pcb, ssr.sch, step-response-accel10.csv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]
2013-11-25 everything there is to
    [controller.kicad_pcb, controller.sch, experiment-summary.ods]
2013-11-27 relay mode. commit before test
2013-11-27 just a small fix
    [main.c]
2014-01-20 add schematics in PDF for people without Kicad
2014-05-18 use expansion header to set I2C address

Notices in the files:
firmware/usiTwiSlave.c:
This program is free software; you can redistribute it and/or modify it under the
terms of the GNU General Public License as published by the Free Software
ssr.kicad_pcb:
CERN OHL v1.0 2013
